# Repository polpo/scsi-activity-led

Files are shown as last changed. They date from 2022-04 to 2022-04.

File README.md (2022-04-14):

# SCSI activity LED adapter #

Do you use a [BlueSCSI](https://github.com/erichelgeson/bluescsi) externally on your classic Macintosh? Do you wish the little hard drive activity light on the Mac still flashed when using it? This adapter will make that happen.

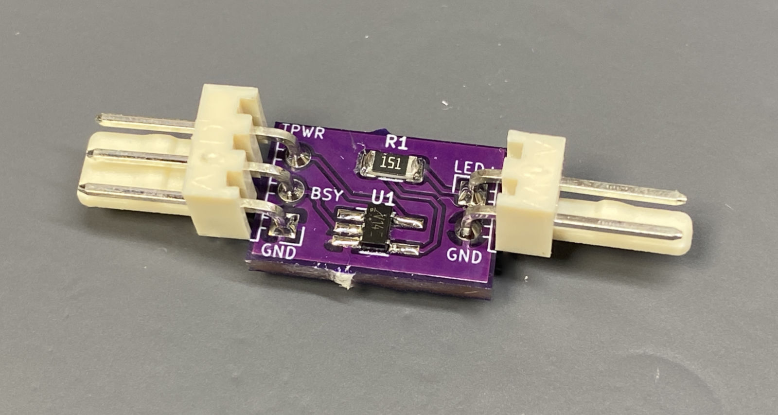
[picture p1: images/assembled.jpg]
assembled SCSI activity LED adapter


This adapter has been tested on a Macintosh SE and Macintosh SE/30. Your mileage may vary with other computers.

## Making the board ##

Submit the gerbers under the gerbers/ directory to your favorite PCB manufacturer. I made mine at [OSH Park](https://oshpark.com/shared_projects/9X7GausD). You can order at that link and as of the time of writing this README, it's only $1.20 for three PCBs!

A BOM is in the [bom.csv](bom.csv) file, consisting of:

- 74LVC1G14 Schmitt trigger logic inverter. I've specifically chosen the Nexperia 74LVC1G14GV,125 because the trigger voltages in its datasheet match the best with SCSI logic levels.
- 2- and 3-pin headers. The 2-pin header is keyed so it fits perfectly with the HD LED connector on the Macintosh SE and SE/30 in the proper orientation.
- One 150 ohm 1206 SMT resistor to limit current to the LED.

Soldering the SMT components shouldn't be too hard even if you don't have SMT soldering experience. Just use plenty of flux, place the parts, and touch the pads with a soldering iron coated with solder.

## Connecting the adapter ##

### 1. Connect to the proper SCSI pins ###

Use 3 dupont connectors to connect the adapter to the following pins on the Macintosh's internal SCSI port:

- TERMPWR: pin 26 - provides power to the adapter. Connect to TPWR on the adapter.
- GND: there are lots of ground pins. Just pick one, like pin 28 which is right next to TERMPWR. Connect to GND on the adapter.
- /BSY: pin 36 - this signal is low when the SCSI bus is in use, and high when the bus is free. Connect to BSY on the adapter.

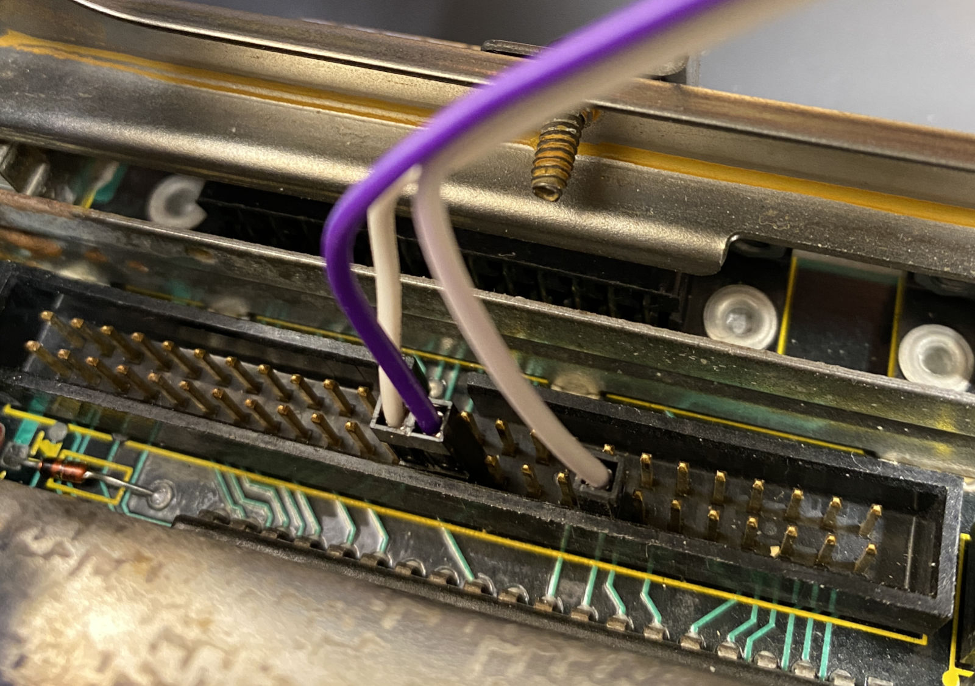
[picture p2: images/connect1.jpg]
connecting to the SCSI port


### 2. Connect the HD activity LED ###

This should plug right in if you're using the LED connector on the Macintosh SE and SE/30.

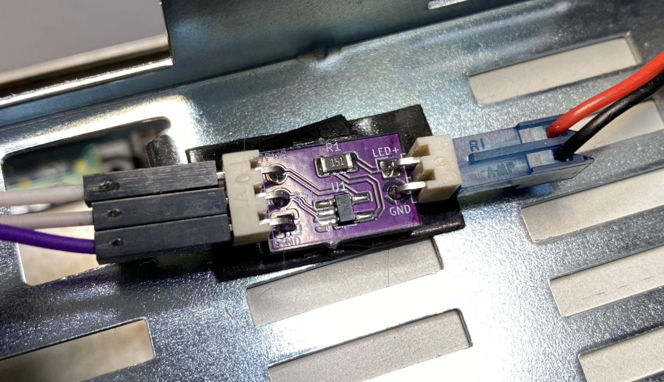
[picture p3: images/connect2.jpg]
connecting the activity LED


### 4. Watch the blinkenlights! ###

Mount the adapter with some double-sided tape so the bottom doesn't short out on the computer's chassis. Turn it on and hopefully you will have a nicely blinking activity LED!

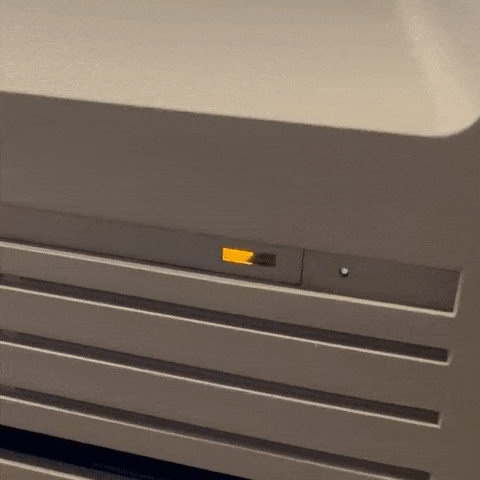
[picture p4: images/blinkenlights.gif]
GIF of blinking hard drive light


## TODO ##

- Design a foolproof version of the adapter that plugs directly into a 50-pin internal SCSI connector.
- Investigate how appropriate other signals on the SCSI bus are for activity lights. I've noticed that when no SCSI devices are connected, the Mac's SCSI controller toggles /BSY continuously, which is annoying.

## License ##

[The project license](LICENSE.txt) is under the CERN Open Hardware Licence Version 2 - Permissive.

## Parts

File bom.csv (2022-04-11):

Index | Manufacturer Part Number | Manufacturer Name | Description | Availability | Stock Status | Attrition % | Requested Quantity 1 | Pack Quantity 1 | Pack Type 1 | Digi-Key Part Number 1 | Unit Price 1 | Extended Price 1 | Minimum Order Quantity 1 | Requested Part Number | Datasheet
1 | 74LVC1G14GV,125 | Nexperia USA Inc. | IC INVERT SCHMITT 1CH 1-IN SC74A | 2,155 | In Stock |  | 1 | 1 | Cut Tape (CT) | 1727-4116-1-ND | 0.37000 | $0.37 | 1 | 1727-4116-1-ND | https://assets.nexperia.com/documents/data-sheet/74LVC1G14.pdf
2 | RMCF1206JT150R | Stackpole Electronics Inc | RES 150 OHM 5% 1/4W 1206 | 443,342 | In Stock |  | 1 | 1 | Cut Tape (CT) | RMCF1206JT150RCT-ND | 0.10000 | $0.10 | 1 | RMCF1206JT150RCT-ND | https://www.seielect.com/catalog/sei-rmcf_rmcp.pdf
3 | LHA-02-TRB | Adam Tech | CONN HEADER R/A 2POS 2.54MM | 5,796 | In Stock |  | 1 | 1 | Bag | 2057-LHA-02-TRB-ND | 0.10000 | $0.10 | 1 | 2057-LHA-02-TRB-ND | https://app.adam-tech.com/products/download/data_sheet/241186/lha-xx-trb-data-sheet.pdf
4 | LHA-03-TRB | Adam Tech | CONN HEADER R/A 3POS 2.54MM | 3,975 | In Stock |  | 1 | 1 | Bag | 2057-LHA-03-TRB-ND | 0.15000 | $0.15 | 1 | 2057-LHA-03-TRB-ND | https://app.adam-tech.com/products/download/data_sheet/241186/lha-xx-trb-data-sheet.pdf

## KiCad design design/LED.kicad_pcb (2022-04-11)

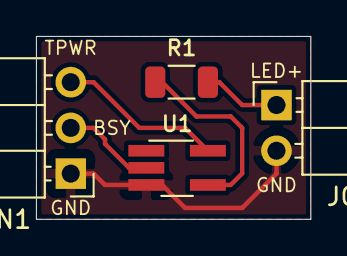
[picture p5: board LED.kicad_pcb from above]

Board: 2 copper layers, 15.2 x 10.2 mm, 4 parts (0 on the bottom side), 5 nets.

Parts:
JIN1: Conn_01x03_Male; PinHeader_1x03_P2.54mm_Horizontal
JOUT1: Conn_01x02_Male; PinHeader_1x02_P2.54mm_Horizontal
R1: 150; R_1206_3216Metric
U1: 74AHC1G04; TSOT-23-5_HandSoldering

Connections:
GND: JIN1.1, JOUT1.2, U1.3
unnamed: JIN1.2, U1.2
unnamed: JOUT1.1, R1.1
unnamed: R1.2, U1.4
VCC: JIN1.3, U1.5
